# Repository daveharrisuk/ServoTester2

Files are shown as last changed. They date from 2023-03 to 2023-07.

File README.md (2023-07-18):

# ServoTester2

Exercise servo movement while monitoring current demand from servo.

Servo movement sweeps either side of mid position 1.50ms duty cycle,
- sweep controlled by a potentiometer, from zero sweep through to max degree of sweep.
- 1000ms after a sweep, the sweep direction changes. 
A toggle switch inhibits the direction change (run or pause).
 While in pause, the servo will track any pot movements.

3 LEDs indicate servo current... (currents are average and NOT peak)
- Less than 250mA then Yellow light.
- Greater than 250mA then Red light.
- Between 25mA and 250mA then Green light.
- UnderVolt(4.70v) or OverAmp(600mA) Yellow blink on at 500ms rate (operation suspended for 2sec).

Revision A - required a 3D printed panel. Rsense was 0R5.

Revision B1 - the PCB is the panel. 
 Rsense reduced to 0R2. Con: reduced minimum detection current. Pro: lower Voltage loss on servo.

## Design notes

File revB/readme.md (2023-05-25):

# ServoTester2 revB

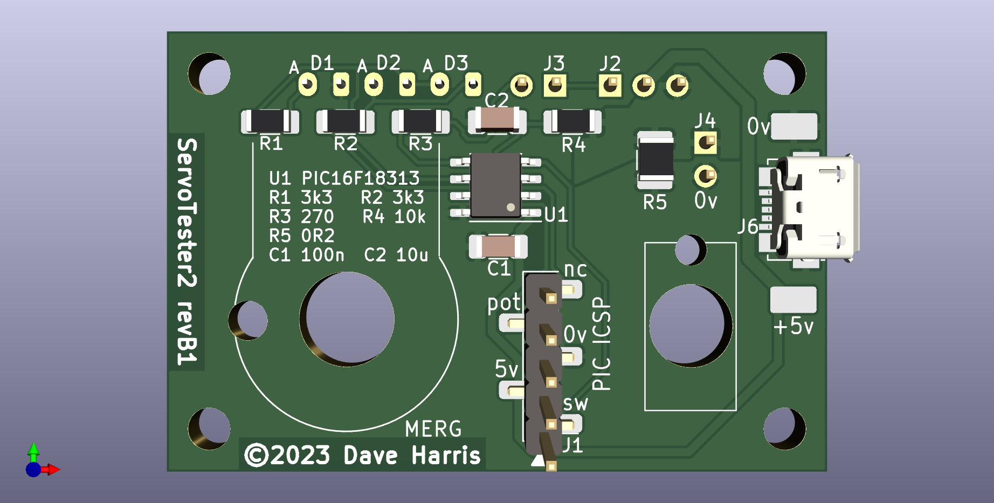
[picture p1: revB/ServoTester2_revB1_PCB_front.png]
revB revB front

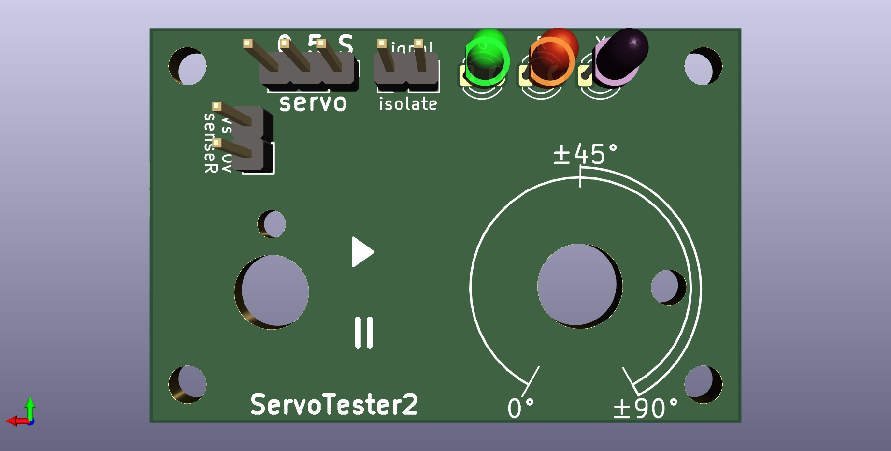
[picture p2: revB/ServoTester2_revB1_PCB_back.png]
revB revB back

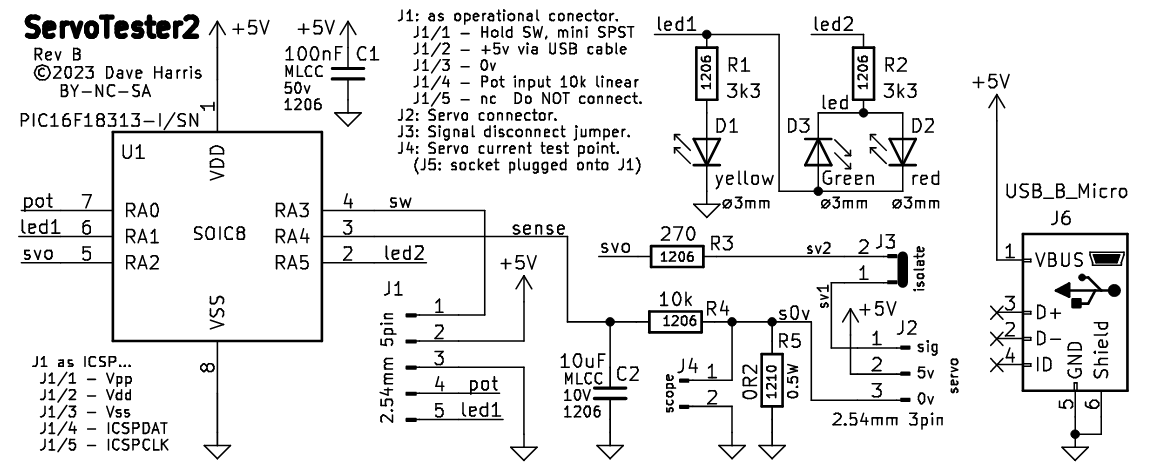
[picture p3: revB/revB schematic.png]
revB revB schematic

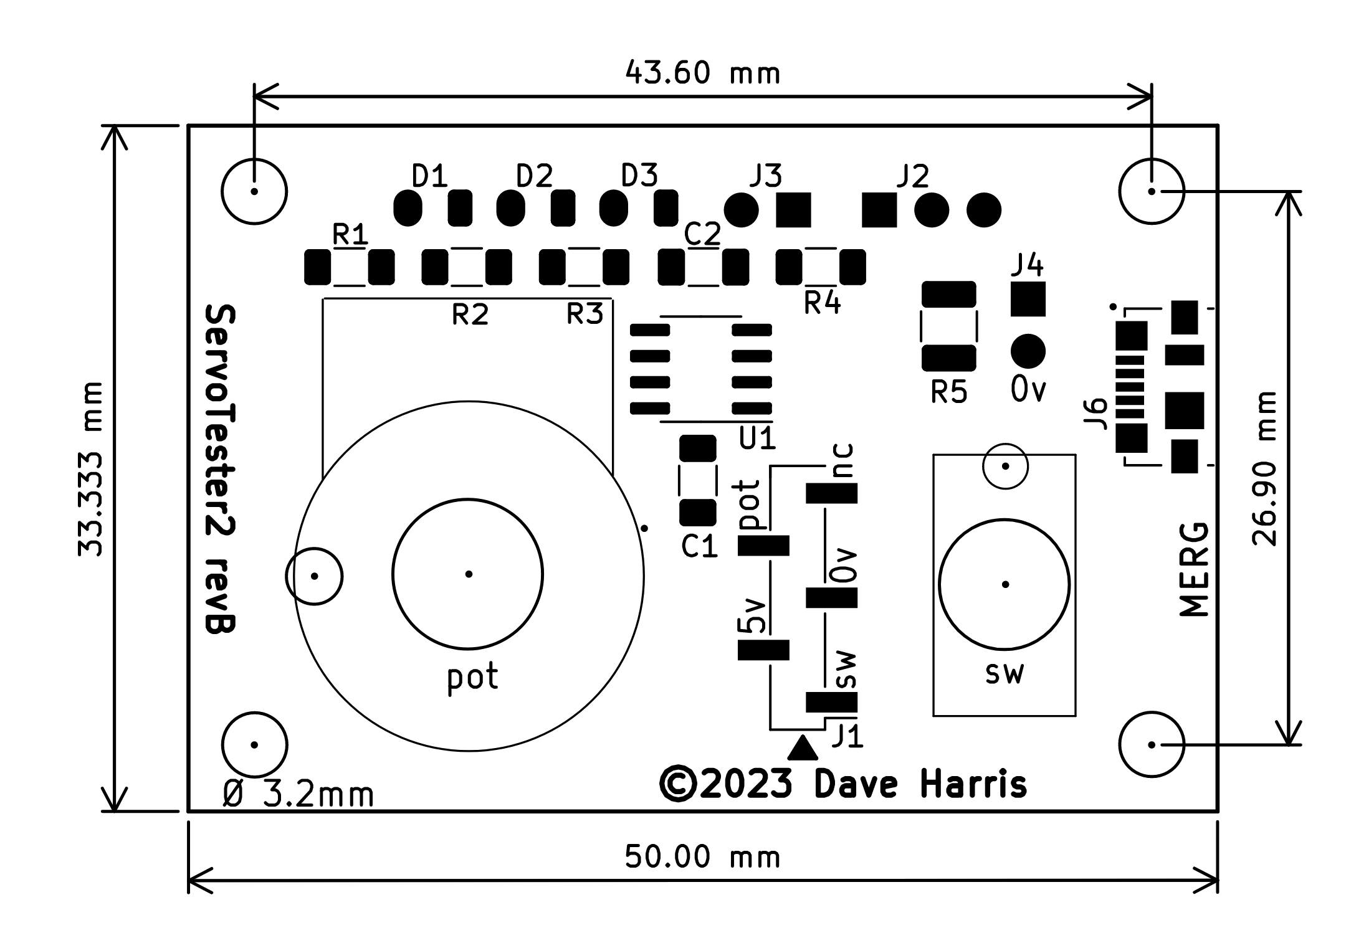
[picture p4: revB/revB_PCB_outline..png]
revB PCB outline


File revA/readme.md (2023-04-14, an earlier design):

# ServoTester2 Rev A
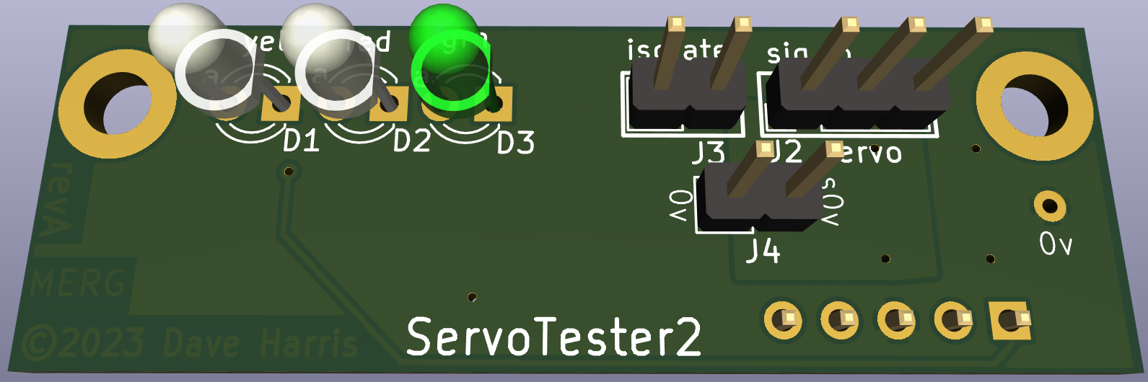
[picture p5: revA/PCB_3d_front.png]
revA PCB front

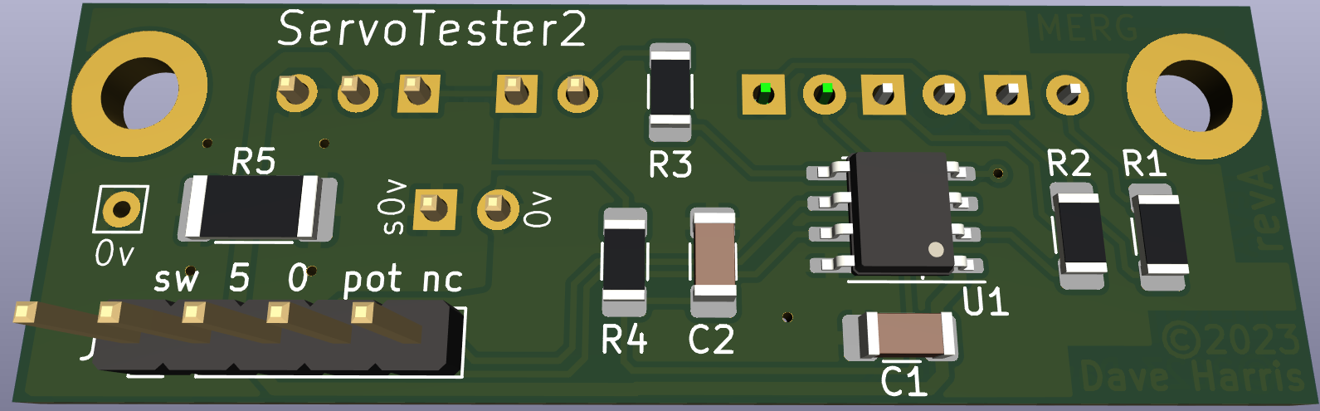
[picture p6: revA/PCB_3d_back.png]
revA PCB back

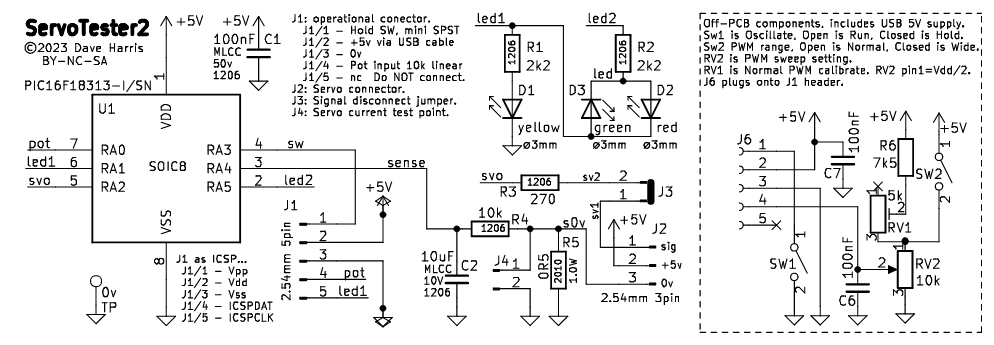
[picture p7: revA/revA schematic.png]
revA schematic

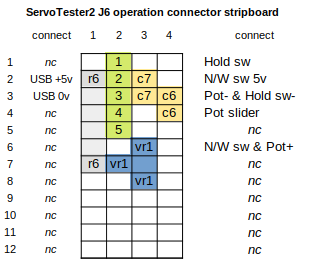
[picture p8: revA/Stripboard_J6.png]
revA


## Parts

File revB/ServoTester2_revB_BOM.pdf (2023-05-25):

Page 1

£each | qty | £cost | ref | type | description | Manufacturer | Part number. | ROHS Compliance
1.07 | 1 | 1.07 | PCB | PCB | 2sided 1.6mm, 50mm x 33.33'mm HASL lead-free | PCBWay | - | 2011/65/EU amended by 2015/863
| | | | | | | Mouser 579-PIC16F18313-I/SN
| | | | | TH T-1(3mm) p2.54mm Red bright low-current | | Mouser 710-151033RS03000
| | | | | TH T-1(3mm) p2.54mm Yellow bright low-current | | Mouser 710-151033YS03000
| | | | | | | Mouser 710-151033GS03000
| | | | | | | Mouser 279-CRG1206F3K3
| | | | | | | Mouser 652-CR1206FX-2700ELF
| | | | | | | Mouser 603-RC1206FR-0710KL
| | | | | | | Mouser 504-MFL1210R2000FS
| | | | | | | Mouser 187-CL31B104KBCNFNC
| | | | | | | Mouser 187-CL31B106KQHNFNE
0.21 | 1 | 0.21 | J2/3/4 | PinHeader | TH p2.54mm SIL, vert, 7way, cut 3+2+2 way | many | Mouser 855-M20-9990746 | 2011/65/EU amended by 2015/863
| | | | | | | Mouser 649-1012938090501BLF
| | | | | SMD USB micro receptacle 5way, type B | | Mouser 649-10118192-0001LF
0.10 | 1 | 0.10 | J3 | Mini-Link | Jumper shunt link 2way pitch 2.54mm | many | Mouser 535-ME-100 | 2011/65/EU amended by 2015/863
0.77 | 1 | 0.77 | U1 | CPU | PIC16F18313-I/SN SOIC8 | Microchip | 2011/65/EU amended by 2015/863 | .
0.14 | 1 | 0.14 | D1 | LED | | Wurth | 2011/65/EU amended by 2015/863 | .
0.14 | 1 | 0.14 | D2 | LED | | Wurth | 2011/65/EU amended by 2015/863 | .
0.22 | 1 | 0.22 | D3 | LED | TH T-1(3mm) p2.54mm Green bright low-current | Wurth | 2011/65/EU amended by 2015/863 | .
0.05 | 2 | 0.09 | R1/R2 | Resistor | SM 1206 3k3 | many | 2011/65/EU amended by 2015/863 | .
0.04 | 1 | 0.04 | R3 | Resistor | SM 1206 270R | many | 2011/65/EU amended by 2015/863 | .
0.04 | 1 | 0.04 | R4 | Resistor | SM 1206 10k | many | 2011/65/EU amended by 2015/863 | .
0.16 | 1 | 0.16 | R5 | Resistor | SM 1210 0R200 0.5W 1% | many | 2011/65/EU amended by 2015/863 | .
0.04 | 1 | 0.04 | C1 | Capacitor | SM 1206 100nF MLCC 50v X7R | many | 2011/65/EU amended by 2015/863 | .
0.06 | 1 | 0.06 | C2 | Capacitor | SM 1206 10uF MLCC 6v3 | many | 2011/65/EU amended by 2015/863 | .
0.13 | 1 | 0.13 | J1 | PinHeader | SMD pitch 2.54mm SIL, vert, 5way | Amphenol FCI | 2011/65/EU amended by 2015/863 | .
0.29 | 1 | 0.29 | J6 | USBsocket | | Amphenol FCI | 2011/65/EU amended by 2015/863 | .

interface circuit

0.08 | 1 | 0.08 | PCB | StripBoard | Pre-cut 2x5 holes (15mm x 7.5mm) pitch 2.54mm | many | Mouser 854-ST3U | 2011/65/EU amended by 2015/863
| | | | | | | Mouser 571-215298-5
| | | | | | | Mouser 652-PDB181-E420K103B
| | | | | | | Mouser 5164-1106WA
| | | | | radial p2.54mm MLCC 100nF 50v X7R | | Mouser 80-C320C104K5R5TATR
0.62 | 1 | 0.62 | SW1 | Switch | Panel minature toggle switch SPST On-Off | many | SwitchElectronics 482839 | Yes
0.71 | 1 | 0.71 | J5 | PinSocket | TH p2.54mm SIL 5way | TE Connectivity | 2011/65/EU amended by 2015/863 | .
1.07 | 1 | 1.07 | RV2 | Pot | 10k linear, shaft 6mm*20mm Knurled/Serrated*18 | Bourns | 2011/65/EU amended by 2015/863 | .
0.85 | 1 | 0.85 | rv2 | Knob | Round pointer, shaft 6mm Knurled/Serrated*18 | DaviesMolding | 2011/65/EU amended by 2015/863 | .
0.08 | 1 | 0.08 | C6 | Capacitor | | many | 2011/65/EU amended by 2015/863 | .
Items | 22 | 6.91 sub total
VAT | 1.38 | 20 %
8.29 | grand total | Dave Harris 24 Apr 2023

ServoTester2 revB BOM

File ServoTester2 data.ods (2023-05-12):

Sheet: pot variance
Bourns-PDB181-E420K-103B ±20%
item | k Ohm | Tolerance
pot1 | 9.85 | -1.50%
pot2 | 10.12 | 1.20%
pot3 | 9.30 | -7.00%
pot4 | 9.99 | -0.10%
pot5 | 9.66 | -3.40%
pot6 | 9.38 | -6.20%
pot7 | 9.19 | -8.10%
pot8 | 10.28 | 2.80%
pot9 | 10.53 | 5.30%
average | 9.81 | -1.89%

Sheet: Pro-Cons
555 timer servo tester
+ | Zero configuration
+ | Low component count | 9
+ | Low cost | £1.39
- | No servo current demand indication
- | Only does ‘normal’ 1ms to 2ms PWM
- | No servo ‘exerciser’ function
- | Poor PWM timing accuracy, due to RC tolerances | t = 0.7CR
 | R Potentiometer (budget) | ± 20%
 | C Capacitor (budget) | ± 10%
PIC based ‘ServoTester2'
+ | Good timing accuracy - PIC Internal Oscillator | ±2%
+ | Switch: Normal 1ms to 2ms or Wide 0.5ms to 2.5ms
+ | Servo current demand indication | 3 | LEDs
+ | Servo ‘exerciser’ function – Oscillate +/- of 1.5ms
+ | Servo signal isolate function
- | Higher component count | 16
- | Higher cost | £9
- | Not zero configuration – load PIC using PICKIT

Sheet: revA header
ServoTester2 revA J6 operation connector stripboard
 | connect | 1 | 2 | 3 | 4 | connect
1 | nc |  | 1 |  |  | Hold sw
2 | USB +5v | r6 | 2 | c7 |  | N/W sw 5v
3 | USB 0v |  | 3 | c7 | c6 | Pot- & Hold sw-
4 | nc |  | 4 |  | c6 | Pot slider
5 | nc |  | 5 |  |  | nc
6 | nc |  |  | vr1 |  | N/W sw & Pot+
7 | nc | r6 | vr1 |  |  | nc
8 | nc |  |  | vr1 |  | nc
9 | nc |  |  |  |  | nc
10 | nc |  |  |  |  | nc
11 | nc |  |  |  |  | nc
12 | nc |  |  |  |  | nc

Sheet: revA BOM
ServoTester2 revA BOM
£each | qty | £cost | ref | type | description | Manufacturer | Mouser part number. | ROHS Compliance
0.74 | 1 | 0.74 | PCB | PCB | 2sided 1.2mm, 50mm x 16.666mm HASL lead-free | PCBWay | - | 2011/65/EU amended by 2015/863
0.77 | 1 | 0.77 | U1 | CPU | PIC16F18313-I/SN SOIC8 | Microchip | 579-PIC16F18313-I/SN | 2011/65/EU amended by 2015/863
0.14 | 1 | 0.14 | D1 | LED | TH T-1(3mm) p2.54mm Red bright low-current | Wurth | 710-151033RS03000 | 2011/65/EU amended by 2015/863
0.14 | 1 | 0.14 | D2 | LED | TH T-1(3mm) p2.54mm Yellow bright low-current | Wurth | 710-151033YS03000 | 2011/65/EU amended by 2015/863
0.22 | 1 | 0.22 | D3 | LED | TH T-1(3mm) p2.54mm Green bright low-current | Wurth | 710-151033GS03000 | 2011/65/EU amended by 2015/863
0.05 | 2 | 0.09 | R1/R2 | Resistor | SM 1206 3k3 | many | 279-CRG1206F3K3 | 2011/65/EU amended by 2015/863
0.04 | 1 | 0.04 | R3 | Resistor | SM 1206 270R | many | 652-CR1206FX-2700ELF | 2011/65/EU amended by 2015/863
0.04 | 1 | 0.04 | R4 | Resistor | SM 1206 10k | many | 603-RC1206FR-0710KL | 2011/65/EU amended by 2015/863
0.21 | 1 | 0.21 | R5 | Resistor | SM 2010 0R5 1.0W 1% | many | 708-CSRN2010FKR500 | 2011/65/EU amended by 2015/863
0.04 | 1 | 0.04 | C1 | Capacitor | SM 1206 100nF MLCC 50v X7R | many | 187-CL31B104KBCNFNC | 2011/65/EU amended by 2015/863
0.06 | 1 | 0.06 | C2 | Capacitor | SM 1206 10uF MLCC 6v3 | many | 187-CL31B106KQHNFNE | 2011/65/EU amended by 2015/863
0.29 | 1 | 0.29 | J1/2/3/4 | PinHeader | TH p2.54mm SIL, 12way – cut up=5+3+2+2 way | many | 855-M20-9771246 | 2011/65/EU amended by 2015/863
0.10 | 1 | 0.10 | J3 | Jumper | Jumper shunt 2way p2.54mm | many | 535-ME-100 | 2011/65/EU amended by 2015/863
interface circuit
0.26 | 1 | 0.26 | PCB | StripBoard | Pre-cut 33*15mm (4x12 holes p2.54mm) | many | 854-ST3U | 2011/65/EU amended by 2015/863
0.71 | 1 | 0.71 | J6 | PinSocket | TH p2.54mm SIL 5way | many | 571-215298-5 | 2011/65/EU amended by 2015/863
1.07 | 1 | 1.07 | RV2 | Pot | 10k linear, shaft 6mm*20mm Knurled/Serrated*18 | Bourns | 652-PDB181-E420K103B | 2011/65/EU amended by 2015/863
0.85 | 1 | 0.85 | rv2 | Knob | Round pointer, shaft 6mm Knurled/Serrated*18 | DaviesMolding | 5164-1106WA | 2011/65/EU amended by 2015/863
0.33 | 1 | 0.33 | RV1 | TrimPot | TH 5k upright side adjustment | Bourns | 652-3306K-1-502 | 2011/65/EU amended by 2015/863
0.04 | 1 | 0.04 | R6 | Resistor | axial 7k5 0.25W 5% | many | 660-CF1/4CT52R752J | 2011/65/EU amended by 2015/863
0.08 | 2 | 0.17 | C6/C7 | Capacitor | radial p2.54mm MLCC 100nF 50v X7R | many | 80-C320C104K5R5TATR | 2011/65/EU amended by 2015/863
0.44 | 1 | 0.44 | SW1 | Switch | Panel rocker switch On-Off | E-Switch | 612-RA12131100 | 2011/65/EU
0.68 | 1 | 0.68 | SW2 | Switch | Panel slide switch On-None-On | Apem | 642-PM13B012 | 2011/65/EU amended by 2015/863
Panel/mountings
0.20 | 1 | 0.20 | panel | panel | 3D printed FDM PLA 2mm x 64mm x 54mm | many | - | -
0.02 | 4 | 0.06 | na | Mounting | M3 CS bolt 8mm. Black coated. | many | - | -
0.02 | 2 | 0.05 | na | Mounting | M3 nut. Plated. | many | - | -
Items | 31 | 7.75 | sub total
 | VAT | 1.55 | 20 | %
 |  | 9.30 | grand total |  | Dave Harris | 28 Mar 23

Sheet: revB BOM
ServoTester2 revB BOM
£each | qty | £cost | ref | type | description | Manufacturer | Part number. | ROHS Compliance
1.07 | 1 | 1.07 | PCB | PCB | 2sided 1.6mm, 50mm x 33.33'mm HASL lead-free | PCBWay | - | 2011/65/EU amended by 2015/863
0.77 | 1 | 0.77 | U1 | CPU | PIC16F18313-I/SN SOIC8 | Microchip | Mouser 579-PIC16F18313-I/SN | 2011/65/EU amended by 2015/863 | .
0.14 | 1 | 0.14 | D1 | LED | TH T-1(3mm) p2.54mm Red bright low-current | Wurth | Mouser 710-151033RS03000 | 2011/65/EU amended by 2015/863 | .
0.14 | 1 | 0.14 | D2 | LED | TH T-1(3mm) p2.54mm Yellow bright low-current | Wurth | Mouser 710-151033YS03000 | 2011/65/EU amended by 2015/863 | .
0.22 | 1 | 0.22 | D3 | LED | TH T-1(3mm) p2.54mm Green bright low-current | Wurth | Mouser 710-151033GS03000 | 2011/65/EU amended by 2015/863 | .
0.05 | 2 | 0.09 | R1/R2 | Resistor | SM 1206 3k3 | many | Mouser 279-CRG1206F3K3 | 2011/65/EU amended by 2015/863 | .
0.04 | 1 | 0.04 | R3 | Resistor | SM 1206 270R | many | Mouser 652-CR1206FX-2700ELF | 2011/65/EU amended by 2015/863 | .
0.04 | 1 | 0.04 | R4 | Resistor | SM 1206 10k | many | Mouser 603-RC1206FR-0710KL | 2011/65/EU amended by 2015/863 | .
0.16 | 1 | 0.16 | R5 | Resistor | SM 1210 0R200 0.5W 1% | many | Mouser 504-MFL1210R2000FS | 2011/65/EU amended by 2015/863 | .
0.04 | 1 | 0.04 | C1 | Capacitor | SM 1206 100nF MLCC 50v X7R | many | Mouser 187-CL31B104KBCNFNC | 2011/65/EU amended by 2015/863 | .
0.06 | 1 | 0.06 | C2 | Capacitor | SM 1206 10uF MLCC 6v3 | many | Mouser 187-CL31B106KQHNFNE | 2011/65/EU amended by 2015/863 | .
0.21 | 1 | 0.21 | J2/3/4 | PinHeader | TH p2.54mm SIL, vert, 7way, cut 3+2+2 way | many | Mouser 855-M20-9990746 | 2011/65/EU amended by 2015/863
0.13 | 1 | 0.13 | J1 | PinHeader | SMD pitch 2.54mm SIL, vert, 5way | Amphenol FCI | Mouser 649-1012938090501BLF | 2011/65/EU amended by 2015/863 | .
0.29 | 1 | 0.29 | J6 | USBsocket | SMD USB micro receptacle 5way, type B | Amphenol FCI | Mouser 649-10118192-0001LF | 2011/65/EU amended by 2015/863 | .
0.10 | 1 | 0.10 | J3 | Mini-Link | Jumper shunt link 2way pitch 2.54mm | many | Mouser 535-ME-100 | 2011/65/EU amended by 2015/863
interface circuit
0.08 | 1 | 0.08 | PCB | StripBoard | Pre-cut 2x5 holes (15mm x 7.5mm) pitch 2.54mm | many | Mouser 854-ST3U | 2011/65/EU amended by 2015/863
0.71 | 1 | 0.71 | J5 | PinSocket | TH p2.54mm SIL 5way | TE Connectivity | Mouser 571-215298-5 | 2011/65/EU amended by 2015/863 | .
1.07 | 1 | 1.07 | RV2 | Pot | 10k linear, shaft 6mm*20mm Knurled/Serrated*18 | Bourns | Mouser 652-PDB181-E420K103B | 2011/65/EU amended by 2015/863 | .
0.85 | 1 | 0.85 | rv2 | Knob | Round pointer, shaft 6mm Knurled/Serrated*18 | DaviesMolding | Mouser 5164-1106WA | 2011/65/EU amended by 2015/863 | .
0.08 | 1 | 0.08 | C6 | Capacitor | radial p2.54mm MLCC 100nF 50v X7R | many | Mouser 80-C320C104K5R5TATR | 2011/65/EU amended by 2015/863 | .
0.62 | 1 | 0.62 | SW1 | Switch | Panel minature toggle switch SPST On-Off | many | SwitchElectronics 482839 | Yes
Items | 22 | 6.91 | sub total
VAT |  | 1.38 | 20 | %
 |  | 8.29 | grand total |  | Dave Harris | 24 Apr 2023

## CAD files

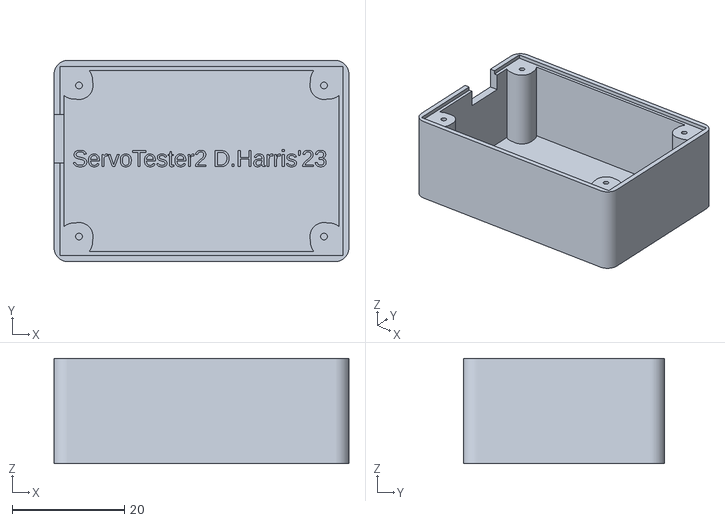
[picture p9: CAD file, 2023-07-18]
ServoTester2_box.stl
52.5 x 35.8 x 18.7

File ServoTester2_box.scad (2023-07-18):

/* ServoTester2_box.scad */
/* © Dave Harris July 2023 */


pcbX = 50;       /* X PCB */
pcbY = 33.3333;  /* Y PCB */
pcbZ = 1.6;      /* PCB thickness */

pcbHoleY = 26.9; /* Y hole spacing */
pcbHoleX = 43.6; /* X hole spacing */
pcbHoleR = 1.6;  /* M3 clearance */

cornerR = 2.5;   /* box corner rad */

boxWall = 1.1;   /* box wall thickness */

pillarR = 2.5;   /* screw pillar rad */
screwR = 0.6;    /* self tap hole */

component = 16;  /* component depth */

boxH = pcbZ +component +boxWall; /* height */


$fn=50;
  


ServoTester2_box(); /* self test module */



/* generate box */

module ServoTester2_box()
{
  difference() /* diff1 */
  {
    union() /* union1 */
    {
      difference() /* diff2 = basic box */
      {
        hull() /* outline with round corner */
          pillar4( pX = pcbX - cornerR
                 , pY = pcbY - cornerR
                 , rad = cornerR
                 , hi = boxH );
        
        /* hollow out box */
        translate([ 0, 0, boxWall + boxH/2 ])
            cube([ pcbX - boxWall
                 , pcbY - boxWall
                 , boxH ], center=true);
        
      } /* end diff2 */
      
      difference() /* diff3 = add pillars */
      {
        union()
        {
          pillar4( pcbHoleX
                 , pcbHoleY
                 , rad = pillarR );
          
          /* infill gaps */
          pillar4( pcbHoleX +1.5
                  , pcbHoleY +1.5
                  , rad = 3.2 );
        }
        /* cut mount screw holes */
        translate([ 0, 0, boxWall ])
          pillar4( pcbHoleX
                 , pcbHoleY
                 , rad = screwR
                 , hi = 20 );
       
      } /* end diff3 */

    } /* end union1 */
    
    /* cutout PCB rebate */
    translate([ 0
              , 0
              , boxWall + component + pcbZ ])
      pcb();
    
    /* cut out USB socket */
    translate([ -28, -0.4, boxH -4.35 ])
      cube([5, 8.7, 4.362]);
    
    translate([-23,-1,boxWall-0.9])
      linear_extrude(1)
        text("ServoTester2 D.Harris'23",3);
    
  } /* end diff1 */
  
  /* illustrate PCB */
  //color("blue") translate([0, 0, 26]) pcb();
  
} /* end module */



/* generate 4 corner pillars */

module pillar4( pX, pY, rad, hi = boxH )
{
  for( x = [-0.5 : 1: 0.5])
  {
    for( y = [-0.5 : 1 : 0.5])
    {
      translate([ x*(pX), y*(pY), 0 ])
       cylinder( h = hi, r = rad );
    }  
  }
} /* end module */



/* generate PCB */

module pcb()
{
  difference()
  {
    cube([pcbX +0.3, pcbY +0.3, pcbZ]
         , center=true);
    translate([0, 0, -1 ])
      pillar4(pX = pcbHoleX
            , pY = pcbHoleY
            , rad = 0.5 );
  }
} /* end module */

 /* end file */

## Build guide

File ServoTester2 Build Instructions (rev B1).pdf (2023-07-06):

# ServoTester2 Build Instructions (rev B1)

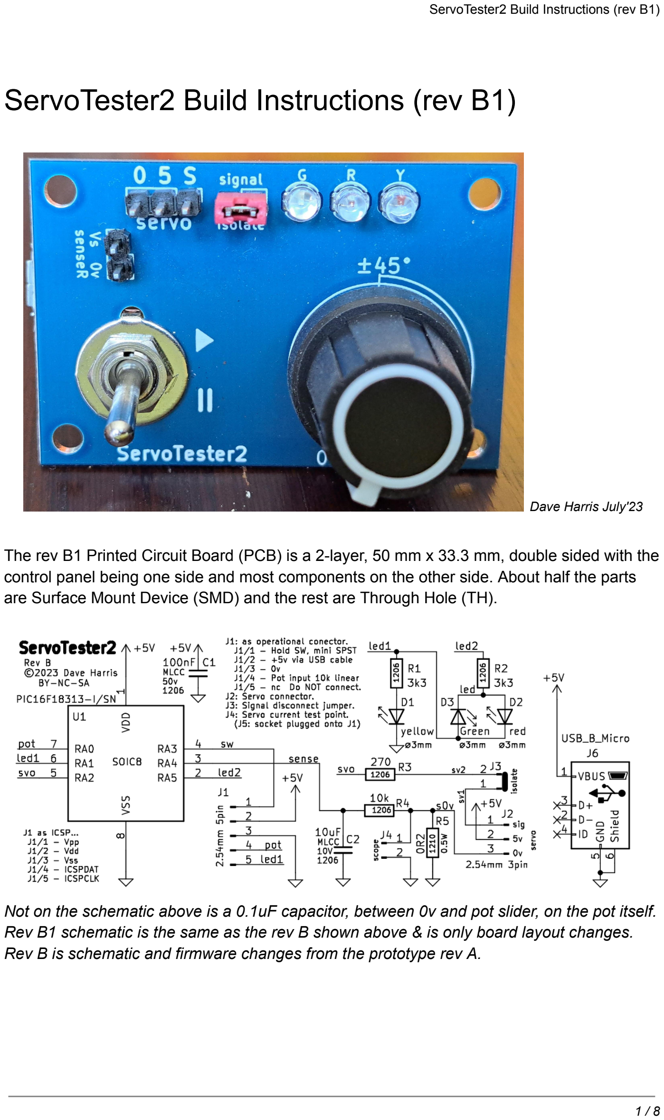
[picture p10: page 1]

ServoTester2 Build Instructions (rev B1)

Dave Harris July'23

The rev B1 Printed Circuit Board (PCB) is a 2-layer, 50 mm x 33.3 mm, double sided with the control panel being one side and most components on the other side. About half the parts are Surface Mount Device (SMD) and the rest are Through Hole (TH).

Not on the schematic above is a 0.1uF capacitor, between 0v and pot slider, on the pot itself. Rev B1 schematic is the same as the rev B shown above & is only board layout changes. Rev B is schematic and firmware changes from the prototype rev A.

1 / 8

These build instructions are for an SMD hand soldering method. The parts will be fitted in an order that ensures nothing impedes the fitting of any other part. The order is SMD parts, Light Emitting Diodes (LED), TH headers and lastly the Potentiometer (pot) and the toggle switch (sw) are fitted, along with their wiring.

For hand soldering SMD, the way I do it, put jelly flux on the mounting pads and place part. Carry solder on the soldering iron tip, to the component pad. The flux will draw the solder from the tip to flow around the pad and component termination to form a solder fillet joint.

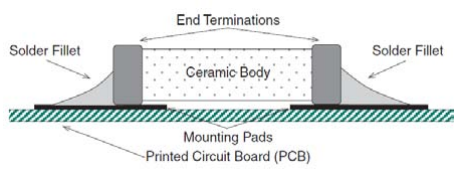
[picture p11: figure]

There are several ways to hand solder SMDs and each way has pros and cons.
I strongly suggest that you check a few YouTube videos to get an idea on how it's done. An alternative to using solder and jelly flux is to use solder paste, again, check it out.

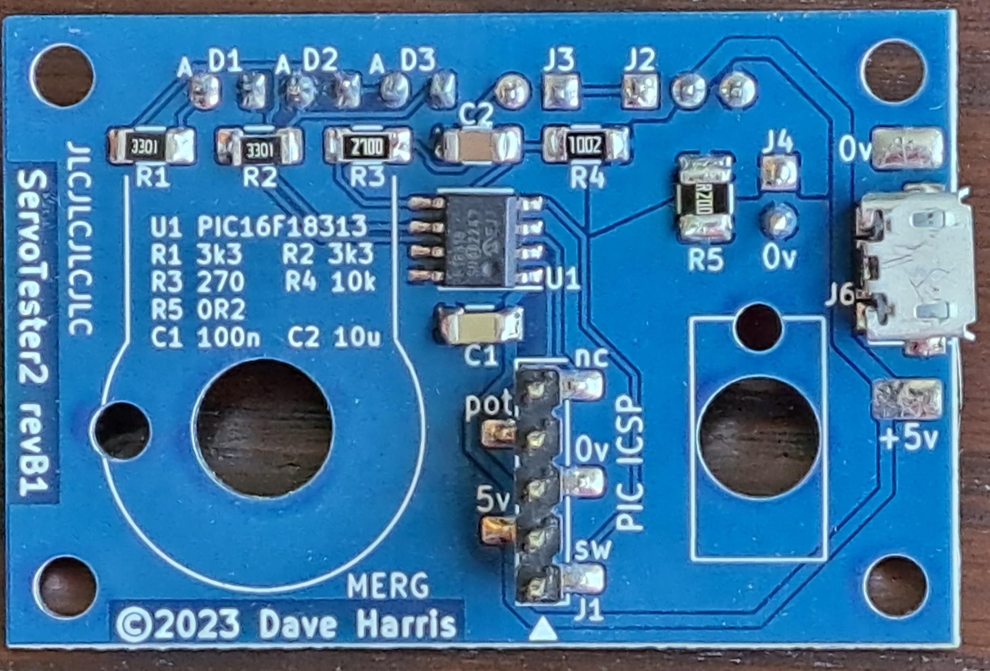
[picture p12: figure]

Your part-built PCB, after a clean up with IPA and a small brush, should look a bit like this.

### I shall be VERY picky here… J6 is not straight and C1 and R2 are off center! So, do as I say and not as I did!

But that said, this example passed all tests OK and works fine.

### Perfection is a target, but not essential!

"Place part, check position, solder one pad, re-check and then solder the other pads"

2 / 8

## Required tools and materials

Temperature controlled soldering iron with a fine tip and fine solder.

SMD rework jelly flux, hypodermic.
EG. Rapid 85-6648 (comes with fine solder)

General tools… Fine point tweezers, wire cutter, long nose plier, wire stripper, ruler, files.

Magnifier or eyeglass, about x10 | Headtorch or desk lamp
Isopropyl Alcohol (IPA) cleaning solution | An old tooth brush for scrubbing PCB clean
A shallow tray/dish for PCB cleaning | LED tester. If your multimeter has more than a 5V battery inside, its 'Diode' test range should be able to test an LED. Try it… Otherwise make your own tester using a 9V PP3 battery and a resistor of around 15k.

Toothpicks

Multimeter - DC Volts & resistance

Solder wick | USB power source, rated more than 2A
Micro USB-USB A cable, Fast Charge type | A known good working servo

PICKIT-4 and PC software (IPE or IDE). Optional: the PIC in the kit may be pre-programmed

## Parts in the kit

The first 12 items are on the parts sheet.

R1 3k3, SMD 1206 | R2 3k3, SMD 1206 | R3 270R, SMD 1206
C2 10uF 6V3, SMD 1206 | R4 10k, SMD 1206 | R5 0R2, SMD 1210
U1 PIC16F18313, SMD SOIC8 | C1 0.1uF 50V, SMD 1206 | D1 yellow LED 3mm, TH
D2 red LED 3mm, TH | D3 green LED 3mm, TH | C3 0.1uF 50V radial 0.1", TH
J1 5 way 0.1" header, SMD | J2/3/4 7 way 0.1" header, TH | J5 5 way 0.1" socket, TH
J6 Micro USB socket, SMD | Shunt strap 0.1" for J3
10k linear pot, panel mount | Knob for the pot | Toggle sw SPST, panel mount
PCB ServoTester2 revB1 | Strip board piece, cut 5x2 holes
110 mm of black wire 7x0.2 | 100 mm of white wire 7x0.2 | 50 mm of red wire 7x0.2
An 'SMD 1206' indicates the parts outline size and equates to 0.012" x 0.006" in size.

3 / 8

# Build Steps

## 1 Start

Read these instructions twice.
Check all the parts are present.
Only detach a component from the parts sheet, WHEN it is needed.
The LEDs and capacitors have NO markings! Capacitor values can be identified using a good digital meter, although in this kit, the 10uF is taller than the 0.1uF. LEDs will need use of an LED tester. The resistors and chip markings will require the use of a magnifier to see & need decoding.

## 2 LED tester

If you already have a tester, goto step 3, or make yourself a simple LED tester…
Solder a ¼ W axial resistor of between 10k to 22k to a PP3 9V battery plus terminal. Solder a length of red wire to the free end of the resistor. Solder a length of black wire to the minus terminal of the battery. On the free ends of the 2 wires (the 'test probes') strip 3 mm of insulation and 'tin' them to ensure the wire strands stay together.
In use, the LED to be tested is connected to the red and black wires. Dab the wires on the the anode, the longer leg, is red wire and the cathode, the shorter leg, the black wire.
An LED can also be tested while in circuit, with module power off.

## 3 Prepare PCB

In a shallow tub give the PCB a scrub clean using IPA and an old toothbrush. Give the PCB a shake to remove excess IPA and allow it to air dry.

## 4 Generic SMD part fitting procedure

Remove selected part (as given in steps 5/6) from the parts sheet and place it on its PCB pads using tweezers, and with a magnifier ensure it is on the pads equally.
Hold part in place with downwards pressure from a toothpick.
Solder one pad only.
Re-check the part is still in the right place. If not then while reflowing the one solder joint, gently turn/push the part with tweezers where it should be.
If the position is good, solder the other pad(s).
With the magnifier check the solder flow is good around the pads.

## 5 Fit USB socket J6 first

USB J6 is not the easiest to solder, so take care with its soldering and the visual inspection. The case is metal for mechanical strength and is soldered on the copper etch ground plane (AKA a heatsink), so you may need to turn up the iron heat there.
Do NOT get flux inside the front or sides of the USB socket, as solder will be drawn in! Note: Pins J6/2, J6/3 & J6/4 are not used, so if their solder is missing, don't worry about it!

4 / 8

With just your finger tips, try to twist the socket. If it moves any, do the soldering again!
Plug in a powered USB cable and test that there is between 4.9V and 5.2V on the 0v and 5v pads. If not then diagnose and fix. Most probably J6/1 or J6/5 solder joint is dry.

## 6 Fit the rest of SMDs

Fit R1, R2, R3, C2, R4, R5, U1, C1 & lastly J1.

For U1 ensure its corner dimple, on the top of its body, is adjacent to the label 'U1' text. R5 is on copper etch heatsink and may need more heat to get a good solder flow.
All other SMDs are orientation and polarity insensitive.

## 7 Fit TH LEDs

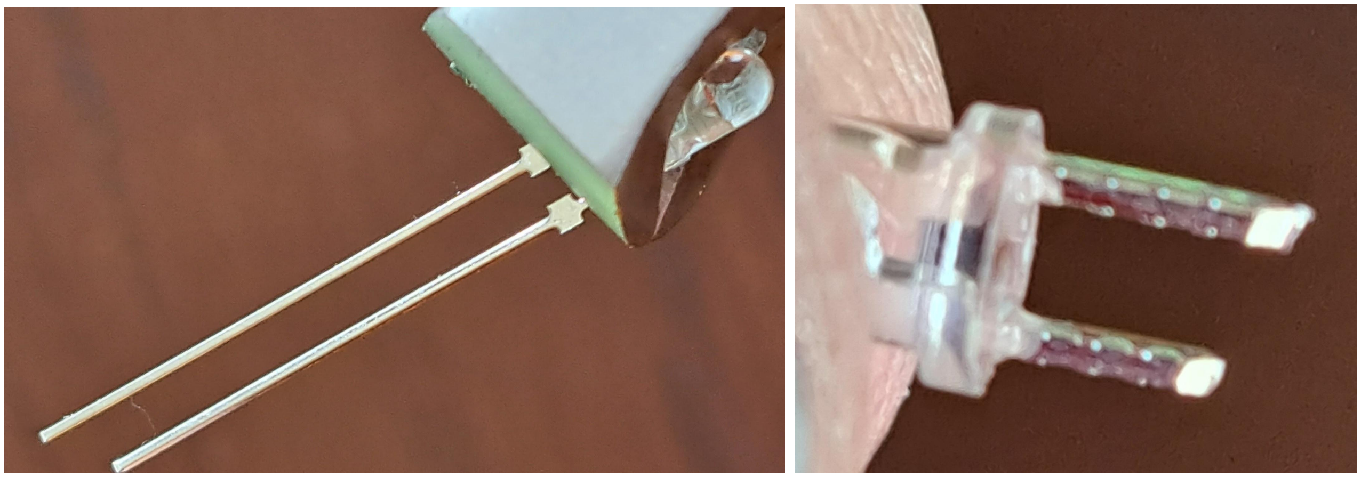
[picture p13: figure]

The square tags on both leads will prevent LED being fitted close to the PCB, so prepare them by cutting both leads at once, but maintain the short and long leg relationship by cutting at an angle.

Solder in the 3 LEDs, on the panel side of the PCB. Since the LEDs are clear plastic and have no ident, check each with the LED tester to confirm their light colour, before soldering. The longer LED leg is the anode pin (shown as 'A' on silk screen). When flush with the panel, solder the other leg.

## 8 Fit TH headers

Cut the header strip three ways, 3 pin, 2 pin and 2 pin.
Fit, on the panel side, the pin headers J2 (3 pin), J3 (2 pin) and J4 (2 pin).
Solder one pin first, if not vertical or is raised from PCB, apply toothpick pressure while reflowing the joint until it is. Then solder the other pin(s).
As J4 is only for a scope connection, my preference is to make its pins shorter.

## 9 Basic inspection and test

Scrub clean using IPA and an old toothbrush. Removing the solder/flux residue from the PCB makes visual inspection easier.
See image on page 2.

5 / 8

Visually check your work with a strong magnifier, looking for missing or incomplete joints.
If you see any, fix by adding flux and re-soldering the affected joints.
If you see solder bridges, these can normally be cleared by adding flux and with no solder on the iron tip, drag the clean tip across the fluxed joints. In bad cases, then use solder wick.

## 10 Electrical Testing

- Do NOT plug in a USB cable.
- Ensure the Shunt Strap is on J3 "signal isolate" and
- there is no servo connected.
Check the resistance readings between the points shown below…
One purpose of the tests is looking to find defective solder joints, the probe should be on the chip pins or component termination cap and NOT on the solder pads.
Another purpose is to ensure the component values are in the right places.
Choose the right meter range: looking for 0 Ω, on the MΩ range may show 0.0 MΩ when it's 500 Ω ! Hold your meter probes together to get a 0 Ω reading, some meters show between 0.5 Ω and 3 Ω ! Measure resistance with meter probe + to -
Test 1. U1/1 pin to J1/2 pin '5v' = 0 Ω | Test 2. U1/2 to D2 anode = 3.3 kΩ ±5%
Test 3. U1/3 pin to J2/3 '0' = 10 kΩ ±5% | Test 4. U1/4 pin to J1/1 'sw' = 0 Ω
Test 5. U1/5 to J2/1 'S' = 270 Ω ±5% | Test 6. U1/6 pin to D1 anode = 3.3 kΩ ±5%
Test 7. U1/7 to J1/4 'pot' = 0 Ω | Test 8. U1/8 pin to J1/3 '0v' = 0 Ω
Test 9. J1/2 to J2/2 '5v' = 0 Ω | Test 10. J1/3 to J2/3 '0v' = 0.2 Ω ±1% *
Test 11. D1 anode to J1/5 'nc' = 3.3 kΩ ±5% | Test 12. +5v pad to 0v pad = greater than 2 MΩ
* Not all meters can measure 0.2 Ω, showing under 1 Ω will be good enough.

Using an LED tester check each LED lights with its correct colour, with plus wire on anode and minus wire on cathode.

If any test fails, do NOT proceed further. Diagnose and fix any faults before proceeding.

## 11 Panel controls

Fit the toggle switch and the pot and knob. When both are straight and tightened, place a small drop of glue on an edge of the nut where it meets the washer.

## 12 J5 connector

Solder the TH header socket into the piece of strip board
(5x2 holes) to form J5.
Plug J5 onto J1 so that the empty holes are toward the pot.

To enable the future fitting of the module into a box, the strip board edge nearest the main PCB edge needs to be filed back to be inline with the end of the J5 socket.

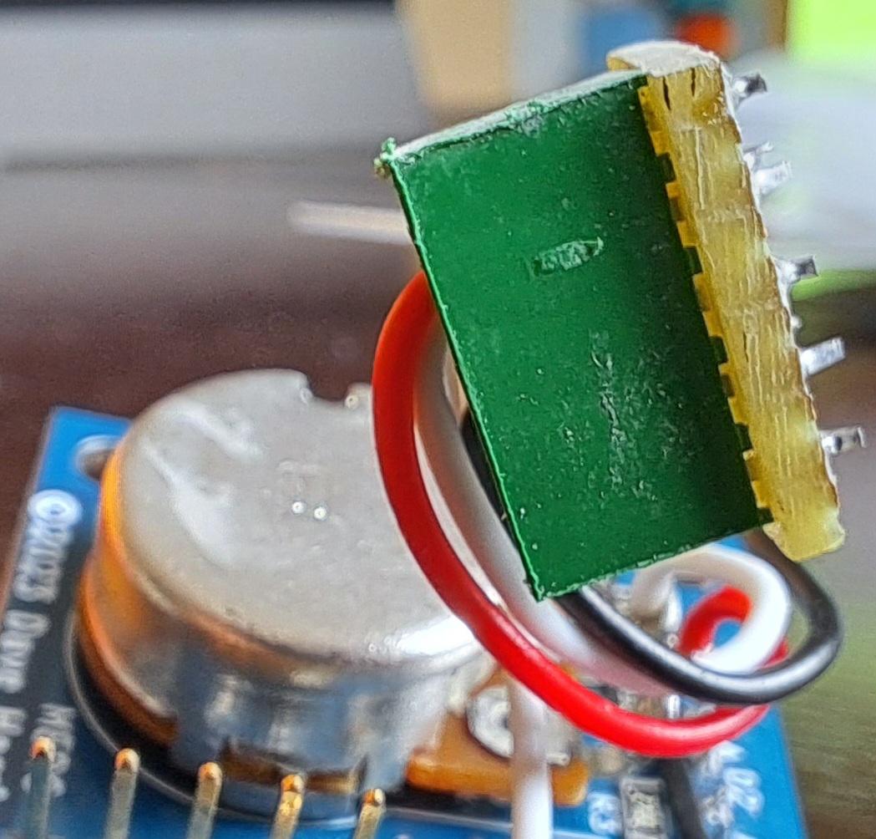
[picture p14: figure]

6 / 8

## 13 Wiring

Fit, but not solder, the 0.1uF radial capacitor to the pot, across the left hand & center lug. It will get solder when the following wires are fitted.
Solder lengths of 7 strand 0.2 mm wire (7/0.2) to this plan. Only strip only about 3 mm of insulation from each wire end and tin.
50 mm white wire from switch upper terminal to J5/1 (sw) (J5/1 is next to the white arrow) 50 mm red wire from pot right hand terminal to J5/2 (5V)
50 mm black wire from pot left hand terminal to J5/3 (0V)
60 mm black wire from the pot left hand terminal to switch center terminal (0V).
50 mm white wire from the pot center terminal to J5/4 (pot) Note J5/5 (nc) has no connection. Route wires as shown in the next image...

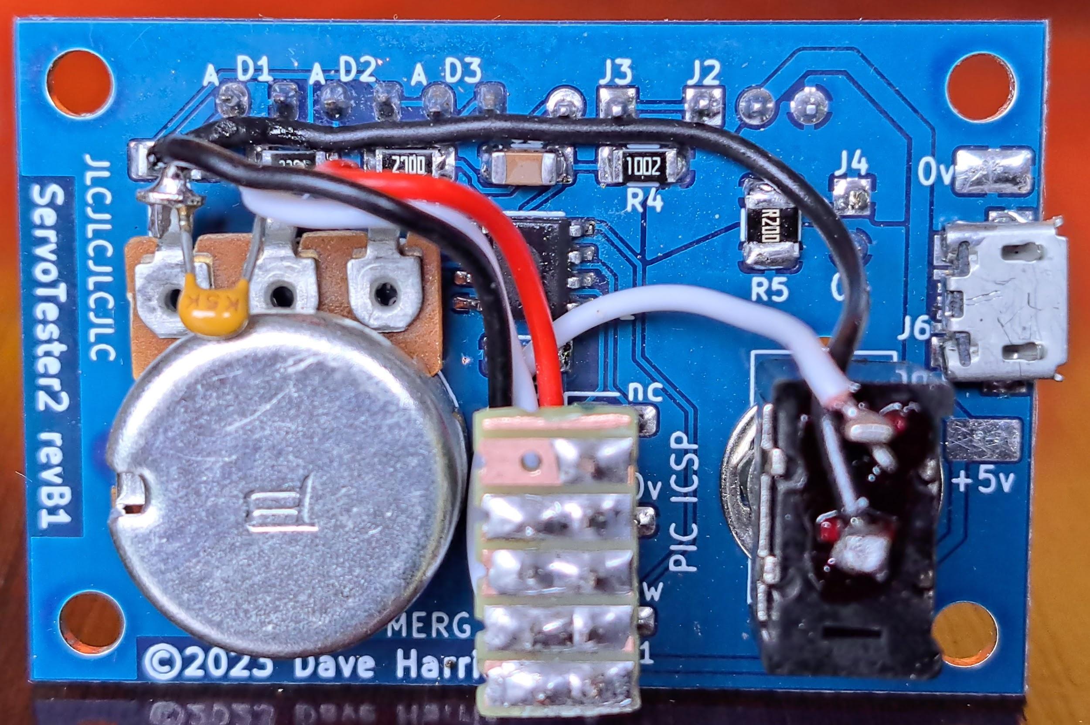
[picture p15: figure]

## 14 Programming the PIC

The kit may be provided with a pre-programmed PIC chip. If so, goto step 15.

In your web browser, goto https://github.com/daveharrisuk/ServoTester2 and download the zip file named like HEX_ServoTester2_v?? which contains firmware hex files. At time of writing the code version is 1.1 and so its name is HEX_ServoTester2_v11.zip Extract the hex file for rev B and this PIC (ServoTester2_revB_v11_PIC16F18313.hex). Unplug J5 from J1, this disconnects the pot and switch, allowing J1 to be used as the "In Circuit Serial Program" (ICSP) header for use by a PICKIT.
Push J5 to one side carefully and plug the PICKIT-4 onto J1. Pin 1 on each is shown by a white arrow. Using the Microchip (microchip.com) IDE or IPE program send the hex file to the PIC. See the Microchip documentation on IPE/IDE for this process. The software should be set to program a PIC16F18313.
The D1 yellow LED will flash while loading is in progress.

7 / 8

## 15 Operation Testing

Before applying power ensure…
- Knob is fully anti clockwise, 0 degrees (No position offset from servo mid position)
- Switch is set to || 'pause' | (No servo position oscillate)
- J5 is on J1 | (The pot and switch are connected to PIC)
- Shunt Strap is on J3 'signal isolate' | (the servo signal is NOT isolated)
- No servo is connected.

Plug in the Micro USB cable. It should be 'Fast Charge' rated type. The USB power source should be capable of supplying 2A.
On power up the LEDs may flash and after that the yellow LED should light and the green and red should be dark.
Test the Voltage on the 0v and 5v pads, there should be between 4.9V to 5.2V, if not then fix. With a temperature probe, check for any hot components (I use the tip of my little finger, if it's hot, it may burn!). Everything should be cool. If anything is hot, power off and investigate.
If other light patterns and previous tests have passed, then suspect the PIC. Contact me via my Github for guidance.

If all is well, then connect a known good servo to J2.
The signal wire (white, yellow or orange) goes next to the pin marked 'S'.
If connected the wrong way, no damage happens, but the servo won't function.
A horn mounted on the servo shaft will help movements to be seen.
The servo should, if not already, move to its center position.
The green LED will flash (greater than 25 mA) while the servo moves. If the green is lit most of the time while the servo is stationary, then it is probably the servo at fault.

Set the switch to 'Run' and gradually turn the knob clockwise. The servo should start a slow oscillating movement and the green LED will flash in time with the movement.

Intermittent red light (greater than 250 mA) can occur with larger servos or with a servo with something impeding its horn movement or of course a suspect servo.

To test the red LED, grip the moving servo horn with your fingers to force a temporary overload. This sounds brutish but I've not had a servo break with this test.
The yellow and green LEDs will go dark and the red LED will light.
If however all the LEDs go dark or the yellow LED flashes (the USB 5V drops below 4.75V), then the USB power source or the cable has not been able to supply enough current.
The modules over current protection is the USB source protection and the USB cable resistance.
The red LED lights when there is more than 250 mA average current. However when the servo's internal Pulse Width Modulation turns on the servo motor, a repetitive peak current greater than an Amp can flow, in short durations. These peaks can reduce the USB power.

End of Document

8 / 8

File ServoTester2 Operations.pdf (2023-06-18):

ServoTester2 Operation (rev B1)

# ServoTester2 Operation (rev B1)

This module operates a 'hobby' 3 wire, 5 Volt, servo that uses a Pulse Width Modulated signal to determine the servo position. The signal repetition is 50 Hz and its pulse high duration is centered on 1.50 ms for servo mid-position. A traditional/early servo has a movement range of 90°, driven by pulses in the range of 1.0 ms to 2.0 ms. A modern servo, generally, has a
movement range of 180°, driven by pulses in the range of 0.5 ms to 2.5 ms.

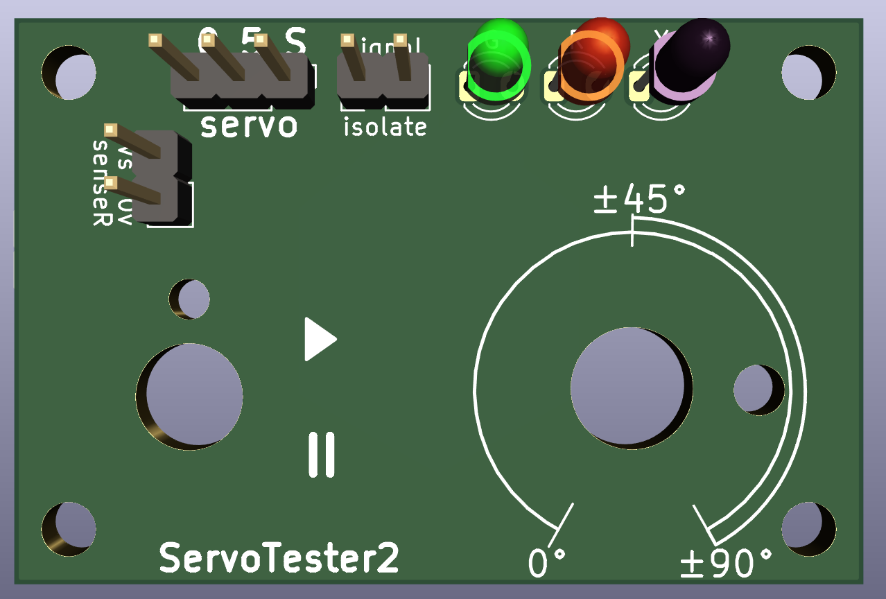
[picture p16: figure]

The ServoTester2 module generates pulses over the 0.5 ms to 2.5 ms range. Beware that 90° servos can be damaged if driven past their limit.

Servo connector.

This 3 pin header for the servo has the legend of 'S 5 0'. The 'S' identifies the signal pin and is normally the orange, yellow or white wire. '5' is the 5V pin and '0' is the 0V pin.

LEDs.

The 3 LEDs indicate the current being pulled by the servo from the 5V supply.
(The currents in the following items are averaged values and NOT peak values)
- Yellow on its own shows less than 25mA is flowing.
- Green plus yellow shows that between 25mA and 250mA flowing.
- Red on its own shows more than 250mA. A larger servo may trigger this.
If the yellow is blinking, and red and green are off, then there is an UnderVolt (<4.75V) fault detected. In a fault state, the module is paused for 2 seconds.

Rotary knob.

This controls how far the signal moves from the 1.5 ms mid-position. Fully counterclockwise the signal is mid-position. Fully clockwise is maximum movement.

Toggle switch.

This enables or pauses an internal 1.0 Hz oscillator. Up is Run and down is Pause. Each phase of the oscillator either adds or subtracts the rotary knob value to/from the mid-position signal of 1.5 ms. With the knob fully counterclockwise, the servo will be stationary in its mid-position. With the knob fully clockwise, the servo will oscillate between its extremes of movement, driven by pulses of 0.5 ms to 2.5 ms. With the knob at half-way rotation, the signal will oscillate between 1.0 ms to 2.0 ms.

author: Dave Harris Jun2023 | p1

ServoTester2 Operation (rev B1)

While in Pause mode, the servo is operating in the add or the subtract phase it was in. To get to the other phase, then do a momentary switch toggle to Run and back to Pause.

Servo Isolate.

For normal use, this 2 pin header has a jumper strap fitted. Removing it, isolates the servo signal, for when investigating how it responds to a loss of signal.

Scope header.

This 2 pin header is for a meter or oscilloscope, when investigating unfiltered current in detail. A small Voltage is developed across an internal current sense of 0.2 Ohm.

USB B micro.

The 5V power. This needs to be a charge rated cable, connected to a 2A rated USB port. For best operation results use a portable USB battery boost charger rated 3A or more. The use of an insubstantial cable or port will cause faults.

End of document.

author: Dave Harris Jun2023 | p2

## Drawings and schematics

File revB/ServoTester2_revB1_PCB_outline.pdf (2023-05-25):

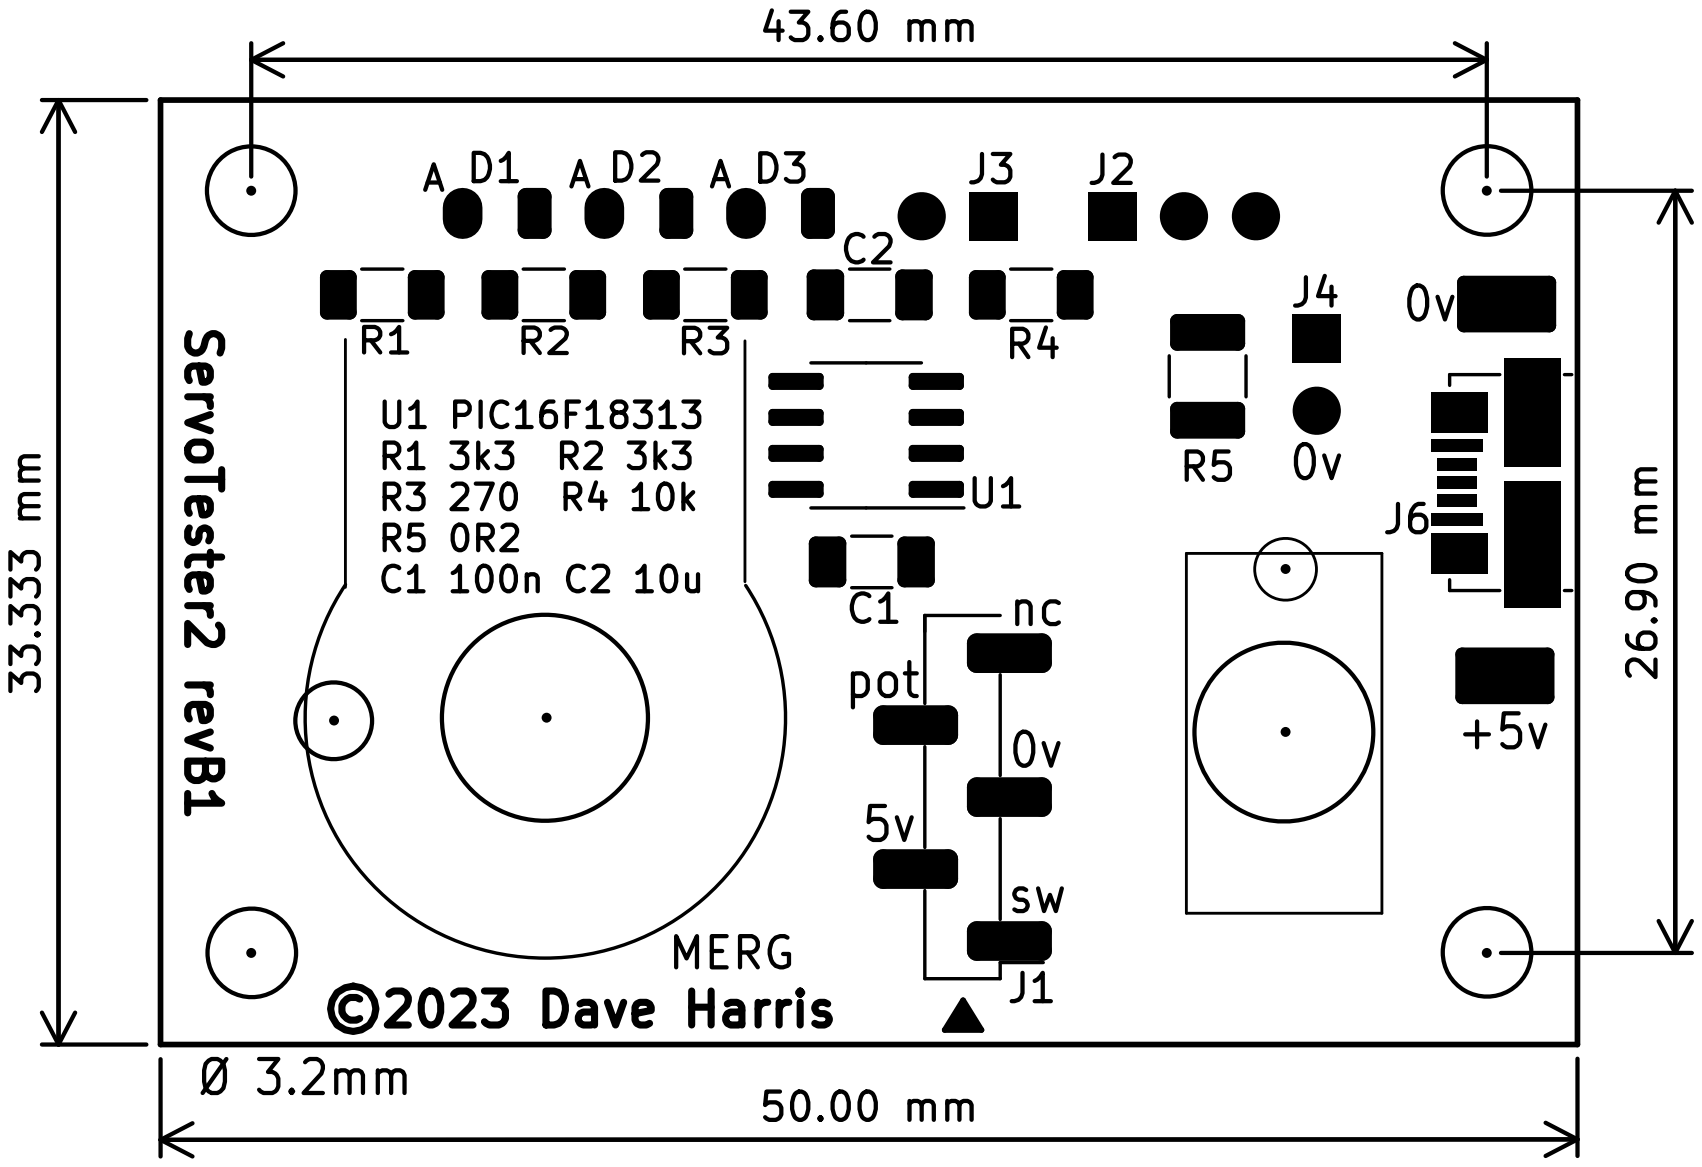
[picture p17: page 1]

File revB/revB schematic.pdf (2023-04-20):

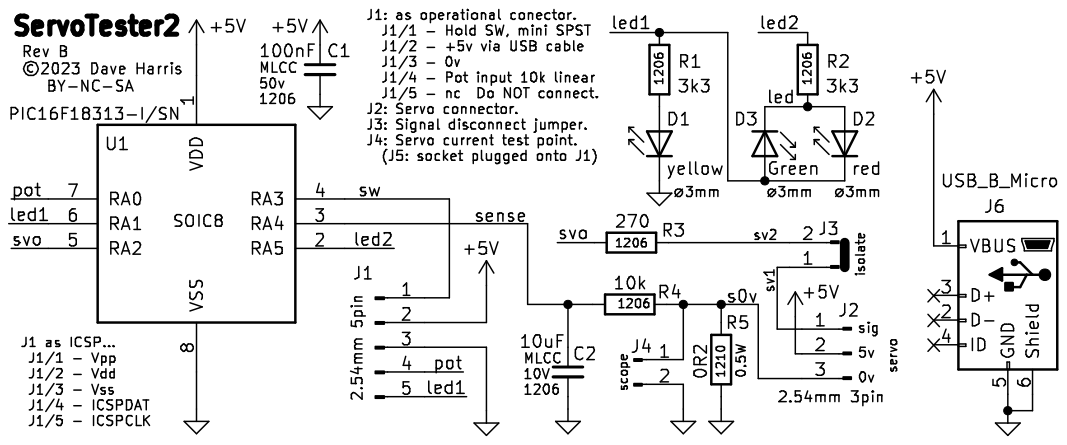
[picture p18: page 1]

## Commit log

2023-03-22 v1 production
    [BOM_ServoTester2.ods]
2023-07-18 add 3D box
    [ServoTester2_box.scad, ServoTester2_box.stl]
